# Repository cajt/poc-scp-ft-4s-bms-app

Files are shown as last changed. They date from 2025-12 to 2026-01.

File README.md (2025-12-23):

# poc-scp-ft-4s-bms-app
Proof of concept fault tolerant SCP with a BMS Application.

# Fault Tolerance Concept

Fail-safe in a 2-out-of-2 configuration. BMS is implemented in split parts. Both halves have to error 
free for the battery/BMS to operate nominally. 
If an error is detected the whole system stops and the electronics disconnects the battery cells from 
the rest of the system, protecting the cells from leaving their safe operating area in the presence 
of BMS error.

In the error-free operation simple cell safety limits are checked: Cell voltages, Current and Temperatures.

# Simplifications for the PoC

- Power supply: Non-redundant and externally supplied.
- Wake-up and power boot-strap: None, the system can't wake up without an external power source. 
- Only 4 cells. (But it should moderately obvious how to extend this by a few more cells. Conceptually this is also compatible with stacking the BMS for higher cells counts.)

# Motivation

Li based cells have some nasty failure-modes, and require some attention to avoid entering dangerous operating areas. This is a good application for fault-tolerance and fail-safe circuitry

# Disclaimer, Liabilities and Guarantees

No Guarantees. The risk is yours alone. If you don't understand this method, mitigation and risks involved you should really not touch this. 
Published in the hope that it might be inspiration or food for thought, not a ready to use module or product.

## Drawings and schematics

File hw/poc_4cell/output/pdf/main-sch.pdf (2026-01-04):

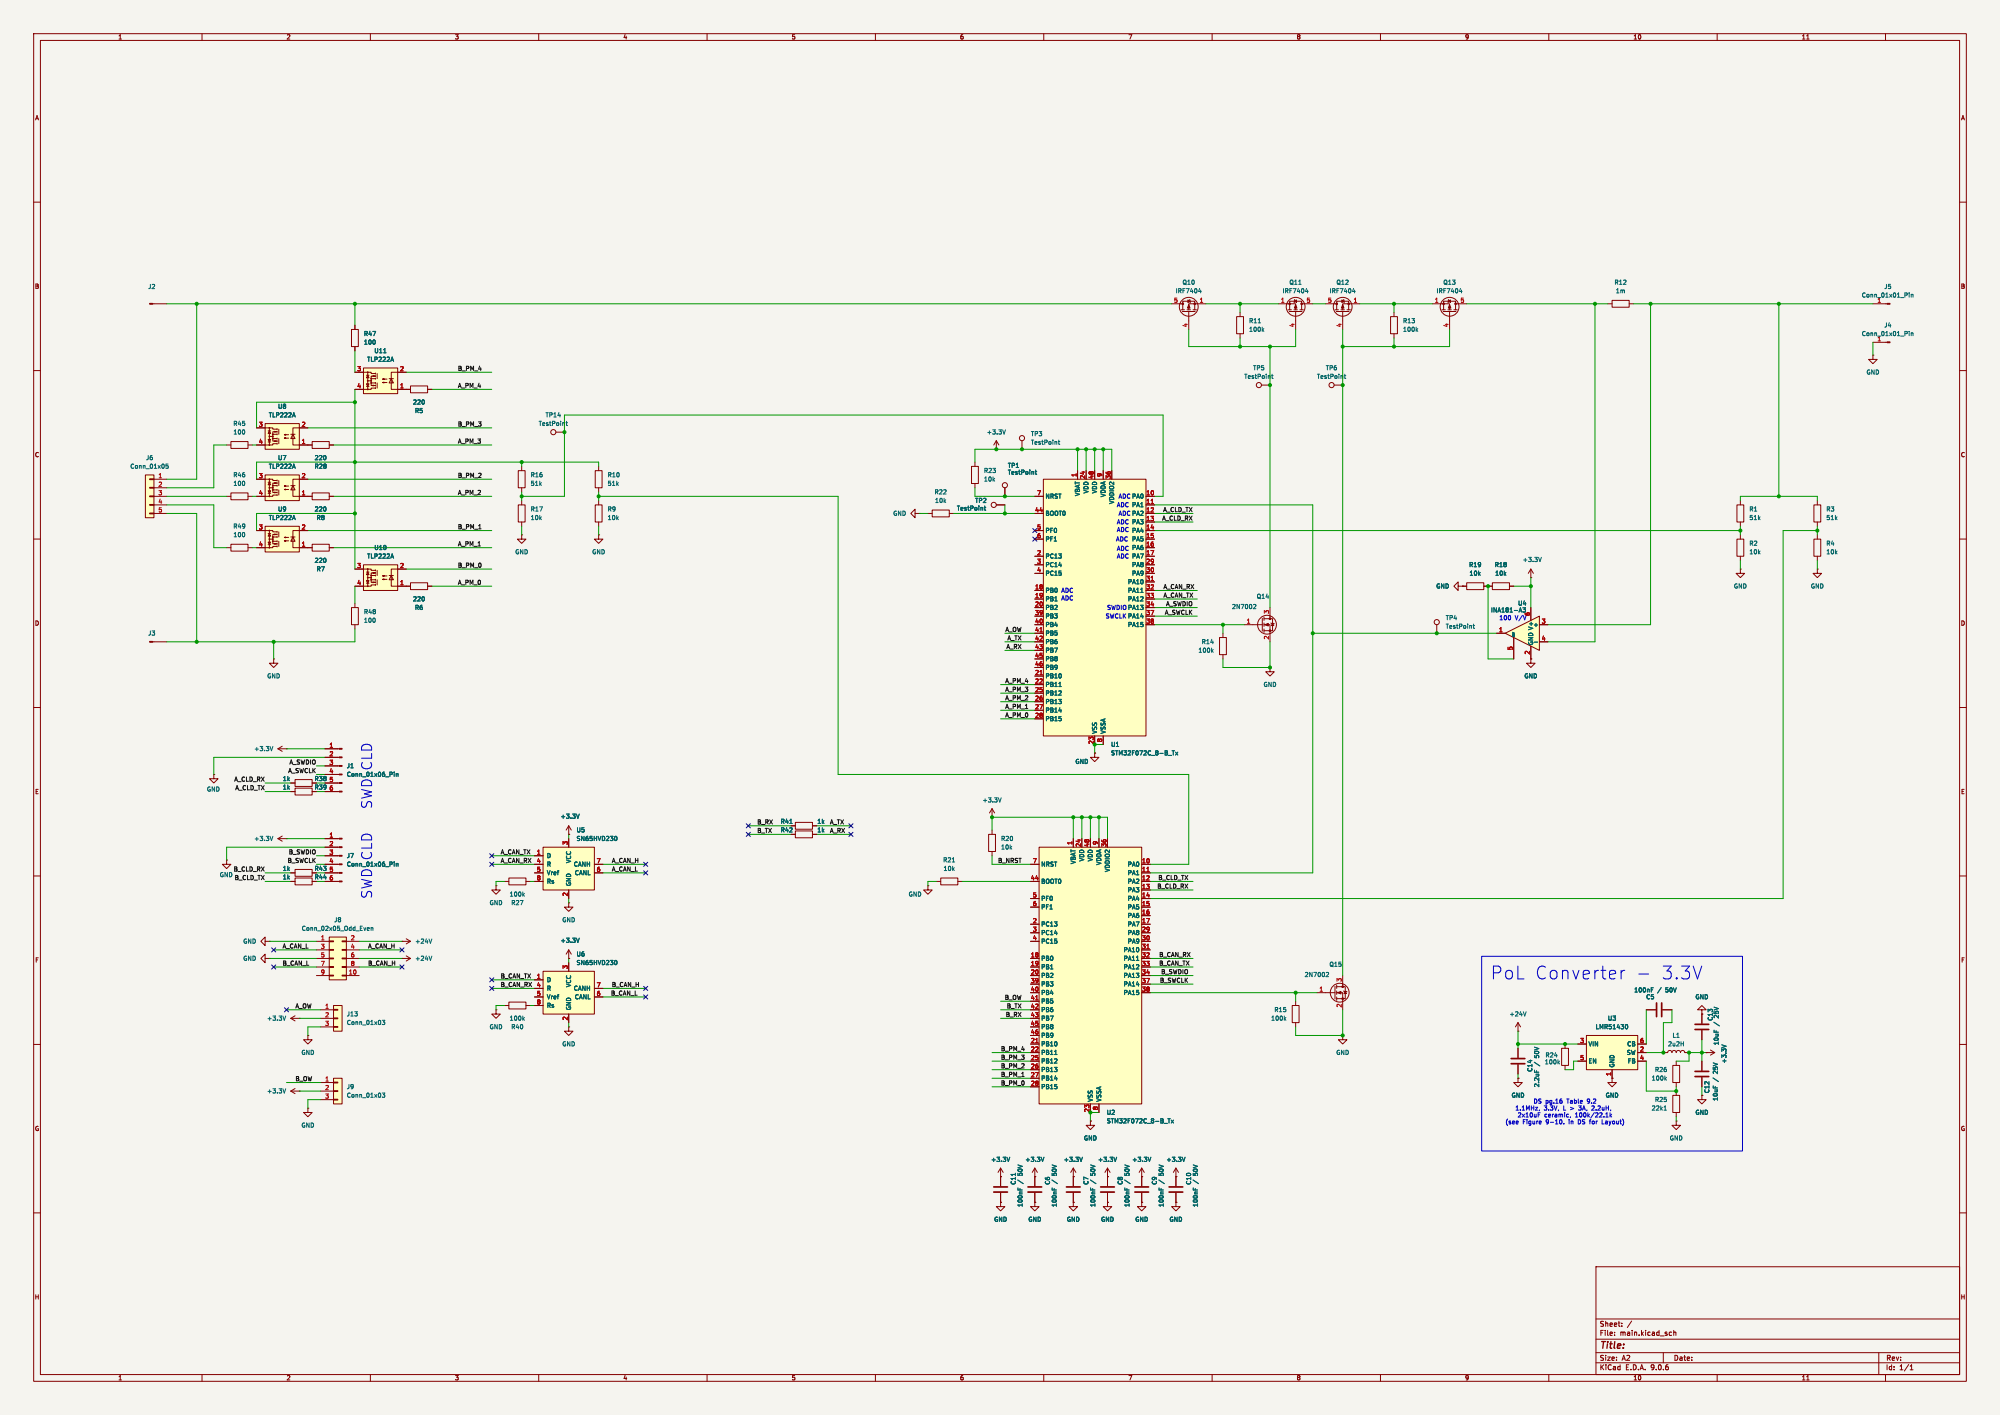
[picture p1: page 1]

1 VDD 24 VDD 48 VSS 23 VDDA

ADC CLD SWD CLD SWD

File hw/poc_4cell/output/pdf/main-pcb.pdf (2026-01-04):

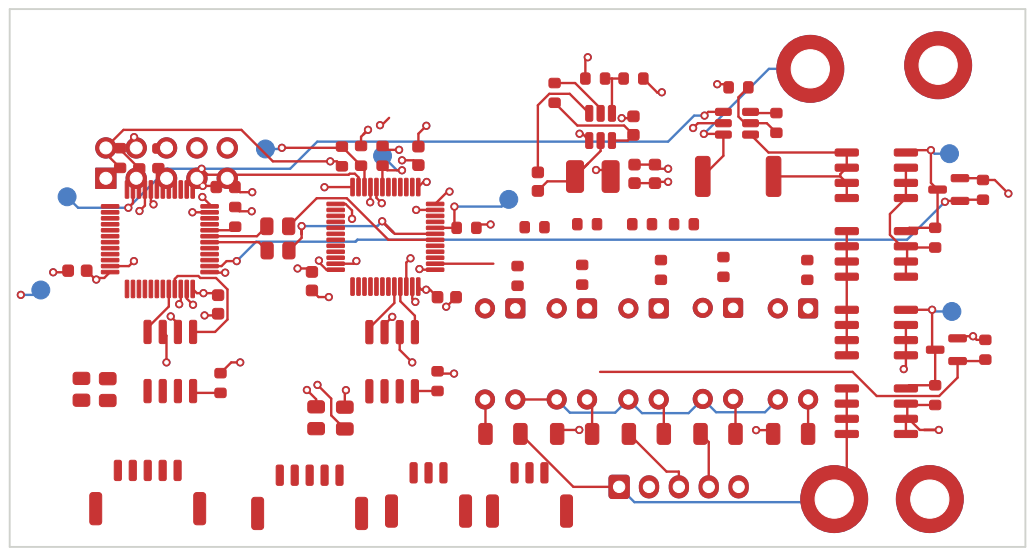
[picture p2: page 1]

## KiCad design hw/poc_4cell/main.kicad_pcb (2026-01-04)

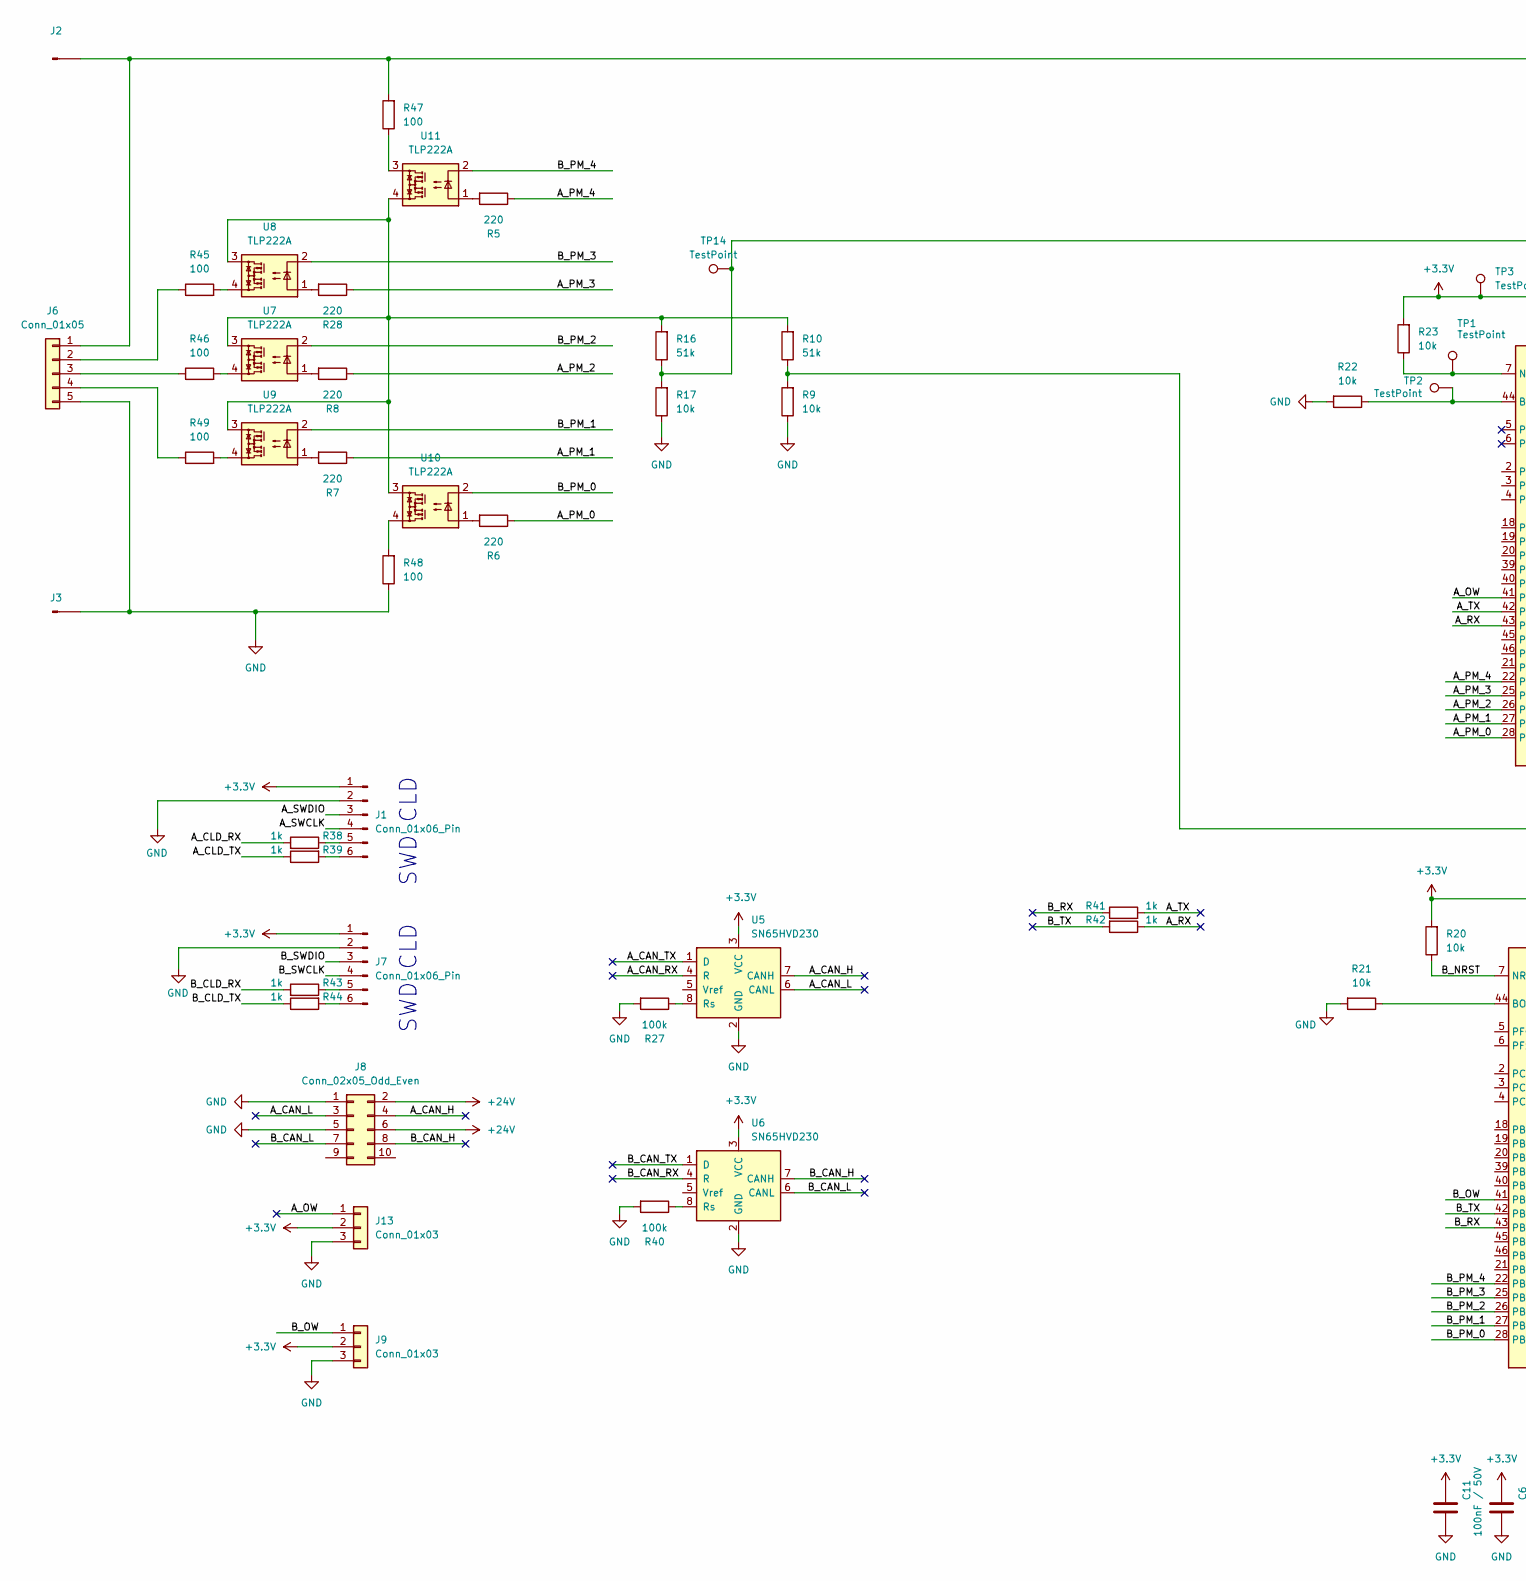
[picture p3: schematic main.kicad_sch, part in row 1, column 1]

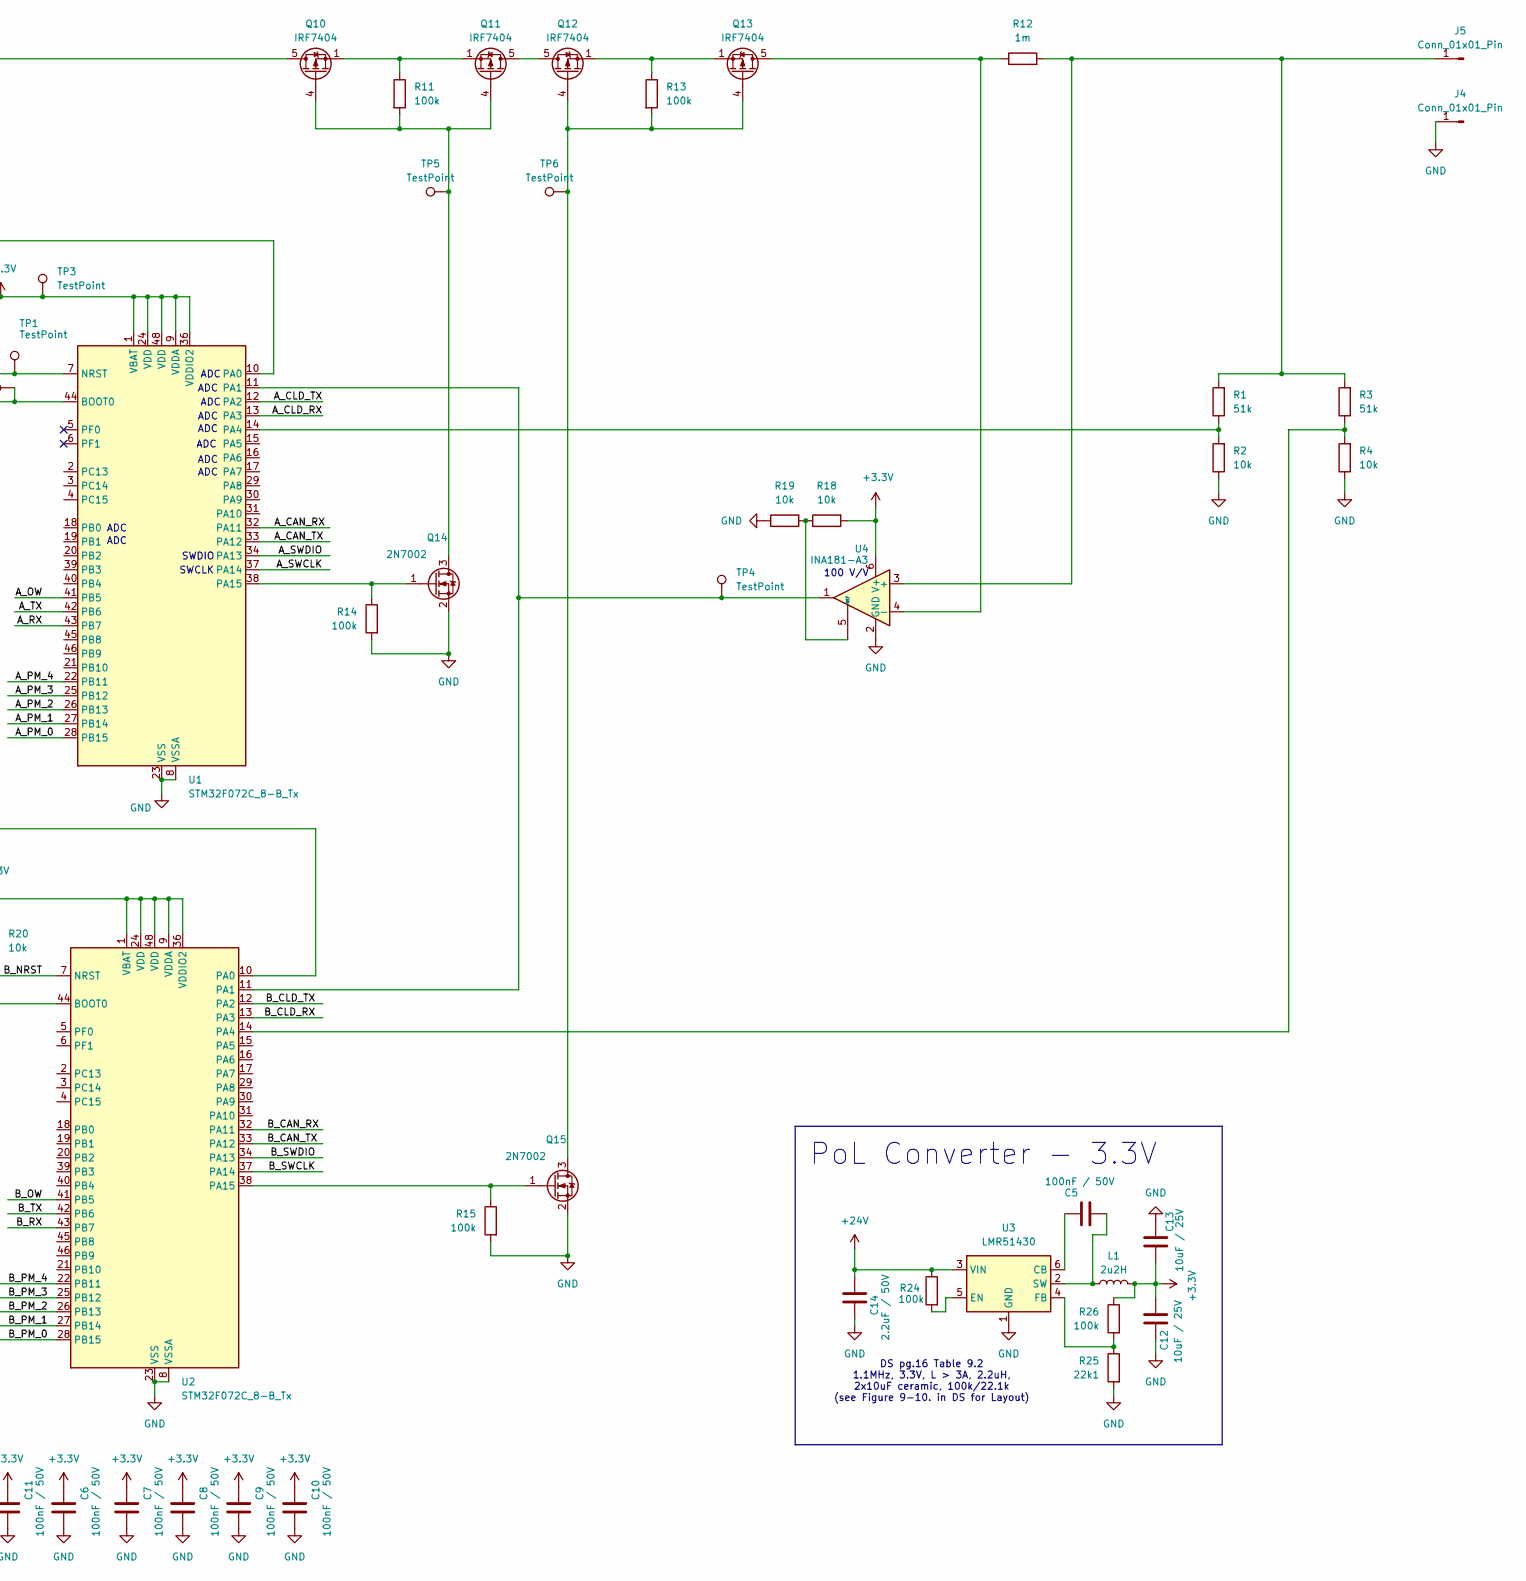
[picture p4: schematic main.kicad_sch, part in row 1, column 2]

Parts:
C5, C6, C7, C8, C9, C10, C11: 100nF / 50V; C_0603_1608Metric
C12, C13: 10uF / 25V; C_0603_1608Metric
C14: 2.2uF / 50V; C_0603_1608Metric
J1, J7: Conn_01x06_Pin; JST_GH_SM05B-GHS-TB_1x05-1MP_P1.25mm_Horizontal
J2, J3, J4, J5: Conn_01x01_Pin; MountingHole_3.2mm_M3_DIN965_Pad
J6: Conn_01x05; JST_XH_B5B-XH-AM_1x05_P2.50mm_Vertical
J8: Conn_02x05_Odd_Even; PinHeader_2x05_P2.54mm_Horizontal
J9, J13: Conn_01x03; JST_GH_SM03B-GHS-TB_1x03-1MP_P1.25mm_Horizontal
L1: 2u2H; L_1210_3225Metric_Pad1.42x2.65mm_HandSolder; mfg# DFE322520F-2R2M=P2
Q10, Q11, Q12, Q13: IRF7404; SOIC-8_3.9x4.9mm_P1.27mm
Q14, Q15: 2N7002; SOT-23
R1, R3, R10, R16: 51k; R_0603_1608Metric
R2, R4, R9, R17, R18, R19, R20, R21, R22, R23: 10k; R_0603_1608Metric
R5, R6, R7, R8, R28: 220; R_0603_1608Metric
R11, R13, R14, R15, R24, R26, R27, R40: 100k; R_0603_1608Metric
R12: 1m; R_2512_6332Metric
R25: 22k1; R_0603_1608Metric
R38, R39, R41, R42, R43, R44: 1k; R_0805_2012Metric
R45, R46, R47, R48, R49: 100; R_1206_3216Metric
TP1, TP2, TP3, TP4, TP5, TP6, TP14: TestPoint; TestPoint_Pad_D1.5mm
U1, U2: STM32F072C_8-B_Tx; LQFP-48_7x7mm_P0.5mm
U3: LMR51430; SOT-23-6
U4: INA181-A3; SOT-23-6
U5, U6: SN65HVD230; SOIC-8_3.9x4.9mm_P1.27mm
U7, U8, U9, U10, U11: TLP222A; DIP-4_W7.62mm

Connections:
+3.3V: C6.1, C7.1, C8.1, C9.1, C10.1, C11.1, C12.1, C13.1, J1.1, J7.1, J9.2, J13.2, L1.2, R18.2, R20.2, R23.2, R26.1, TP3.1, U1.1 (VBAT), U1.9 (VDDA), U1.24 (VDD), U1.36 (VDDIO2), U1.48 (VDD), U2.1 (VBAT), U2.9 (VDDA), U2.24 (VDD), U2.36 (VDDIO2), U2.48 (VDD), U4.6 (V+), U5.3 (VCC), U6.3 (VCC)
+24V: C14.1, J8.2, J8.6, R24.1, U3.3 (VIN)
/A_CAN_H: J8.4, U5.7 (CANH)
/A_CAN_L: J8.3, U5.6 (CANL)
/A_CAN_RX: U1.32 (PA11), U5.4 (R)
/A_CAN_TX: U1.33 (PA12), U5.1 (D)
/A_CLD_RX: R38.2, U1.13 (PA3)
/A_CLD_TX: R39.1, U1.12 (PA2)
/A_OW: J13.1, U1.41 (PB5)
/A_PM_0: R6.1, U1.28 (PB15)
/A_PM_1: R7.1, U1.27 (PB14)
/A_PM_2: R8.1, U1.26 (PB13)
/A_PM_3: R28.1, U1.25 (PB12)
/A_PM_4: R5.1, U1.22 (PB11)
/A_RX: R42.1, U1.43 (PB7)
/A_SWCLK: J1.4, U1.37 (PA14)
/A_SWDIO: J1.3, U1.34 (PA13)
/A_TX: R41.2, U1.42 (PB6)
/B_CAN_H: J8.8, U6.7 (CANH)
/B_CAN_L: J8.7, U6.6 (CANL)
/B_CAN_RX: U2.32 (PA11), U6.4 (R)
/B_CAN_TX: U2.33 (PA12), U6.1 (D)
/B_CLD_RX: R43.2, U2.13 (PA3)
/B_CLD_TX: R44.1, U2.12 (PA2)
/B_NRST: R20.1, U2.7 (NRST)
/B_OW: J9.1, U2.41 (PB5)
/B_PM_0: U2.28 (PB15), U10.2
/B_PM_1: U2.27 (PB14), U9.2
/B_PM_2: U2.26 (PB13), U7.2
/B_PM_3: U2.25 (PB12), U8.2
/B_PM_4: U2.22 (PB11), U11.2
/B_RX: R41.1, U2.43 (PB7)
/B_SWCLK: J7.4, U2.37 (PA14)
/B_SWDIO: J7.3, U2.34 (PA13)
/B_TX: R42.2, U2.42 (PB6)
GND: C6.2, C7.2, C8.2, C9.2, C10.2, C11.2, C12.2, C13.2, C14.2, J1.2, J3.1, J4.1, J6.5, J7.2, J8.1, J8.5, J9.3, J13.3, Q14.2 (S), Q15.2 (S), R2.1, R4.1, R9.1, R14.2, R15.2, R17.1, R19.1, R21.2, R22.2, R25.2, R27.2, R40.2, R48.1, U1.8 (VSSA), U1.23 (VSS), U1.35 (VSS), U1.47 (VSS), U2.8 (VSSA), U2.23 (VSS), U2.35 (VSS), U2.47 (VSS), U3.1 (GND), U4.2 (GND), U5.2 (GND), U6.2 (GND)
unnamed: J1.5, R38.1
unnamed: J1.6, R39.2
unnamed: J2.1, J6.1, Q10.5 (D), Q10.6 (D), Q10.7 (D), Q10.8 (D), R47.2
unnamed: J5.1, R1.2, R3.2, R12.2, U4.3 (+)
unnamed: J6.2, R45.1
unnamed: J6.3, R46.1
unnamed: J6.4, R49.1
unnamed: J7.5, R43.1
unnamed: J7.6, R44.2
unnamed: Q10.4 (G), Q11.4 (G), Q14.3 (D), R11.2, TP5.1
unnamed: Q10.1 (S), Q10.2 (S), Q10.3 (S), Q11.1 (S), Q11.2 (S), Q11.3 (S), R11.1
unnamed: Q11.5 (D), Q11.6 (D), Q11.7 (D), Q11.8 (D), Q12.5 (D), Q12.6 (D), Q12.7 (D), Q12.8 (D)
unnamed: Q12.4 (G), Q13.4 (G), Q15.3 (D), R13.2, TP6.1
unnamed: Q12.1 (S), Q12.2 (S), Q12.3 (S), Q13.1 (S), Q13.2 (S), Q13.3 (S), R13.1
unnamed: Q14.1 (G), R14.1, U1.38 (PA15)
unnamed: Q15.1 (G), R15.1, U2.38 (PA15)
unnamed: R5.2, U11.1
unnamed: R6.2, U10.1
unnamed: R7.2, U9.1
unnamed: R8.2, U7.1
unnamed: R10.2, R16.2, U7.3, U8.3, U9.3, U10.3, U11.4
unnamed: R28.2, U8.1
unnamed: R45.2, U8.4
unnamed: R46.2, U7.4
unnamed: R47.1, U11.3
unnamed: R48.2, U10.4
unnamed: R49.2, U9.4
unnamed: R22.1, TP2.1, U1.44 (BOOT0)
unnamed: R23.1, TP1.1, U1.7 (NRST)
unnamed: R16.1, R17.2, TP14.1, U1.10 (PA0)
unnamed: TP4.1, U1.11 (PA1), U2.11 (PA1), U4.1
unnamed: R1.1, R2.2, U1.14 (PA4)
unnamed: R21.1, U2.44 (BOOT0)
unnamed: R9.2, R10.1, U2.10 (PA0)
unnamed: R3.1, R4.2, U2.14 (PA4)
unnamed: C5.1, U3.6 (CB)
unnamed: R24.2, U3.5 (EN)
unnamed: R25.1, R26.2, U3.4 (FB)
unnamed: C5.2, L1.1, U3.2 (SW)
unnamed: Q13.5 (D), Q13.6 (D), Q13.7 (D), Q13.8 (D), R12.1, U4.4 (-)
unnamed: R18.1, R19.2, U4.5 (REF)
unnamed: R27.1, U5.8 (Rs)
unnamed: R40.1, U6.8 (Rs)

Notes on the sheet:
SWCLK
ADC
CLD
SWD
DS pg.16 Table 9.2 1.1MHz, 3.3V, L > 3A, 2.2uH, 2x10uF ceramic, 100k/22.1k (see Figure 9-10. in DS for Layout)
PoL Converter - 3.3V
100 V/V
SWDIO

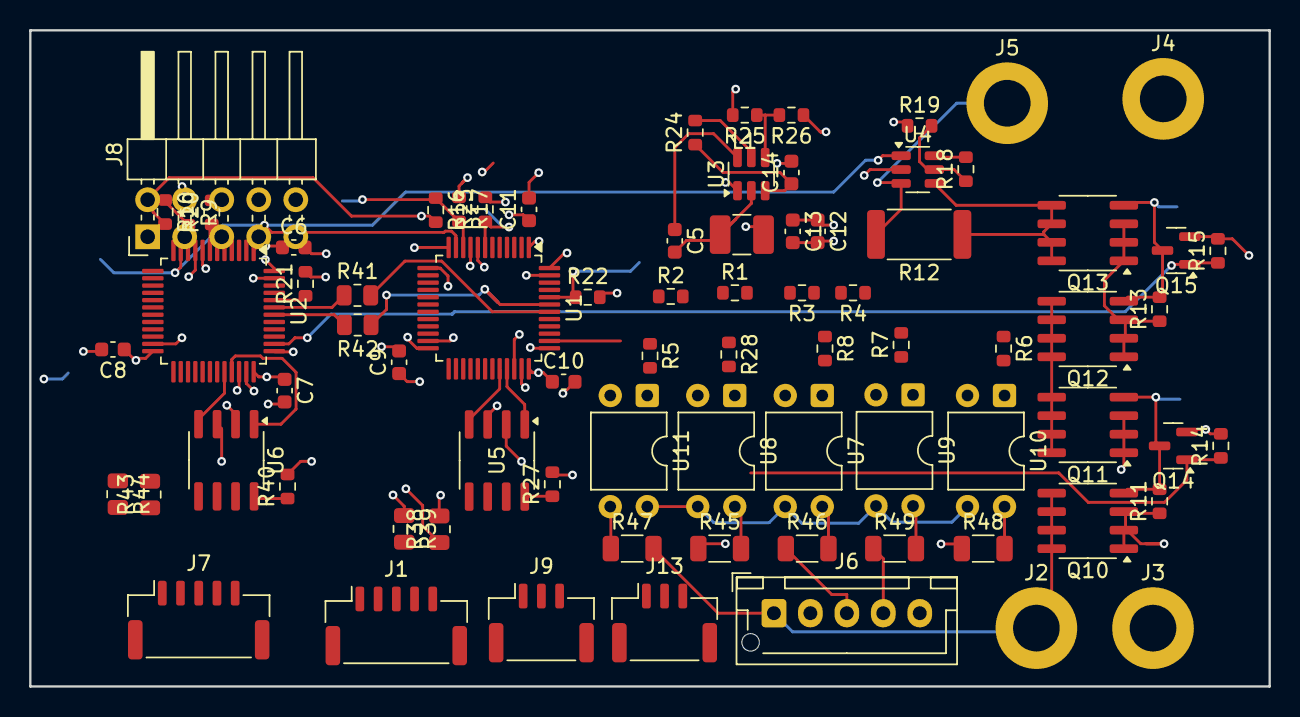
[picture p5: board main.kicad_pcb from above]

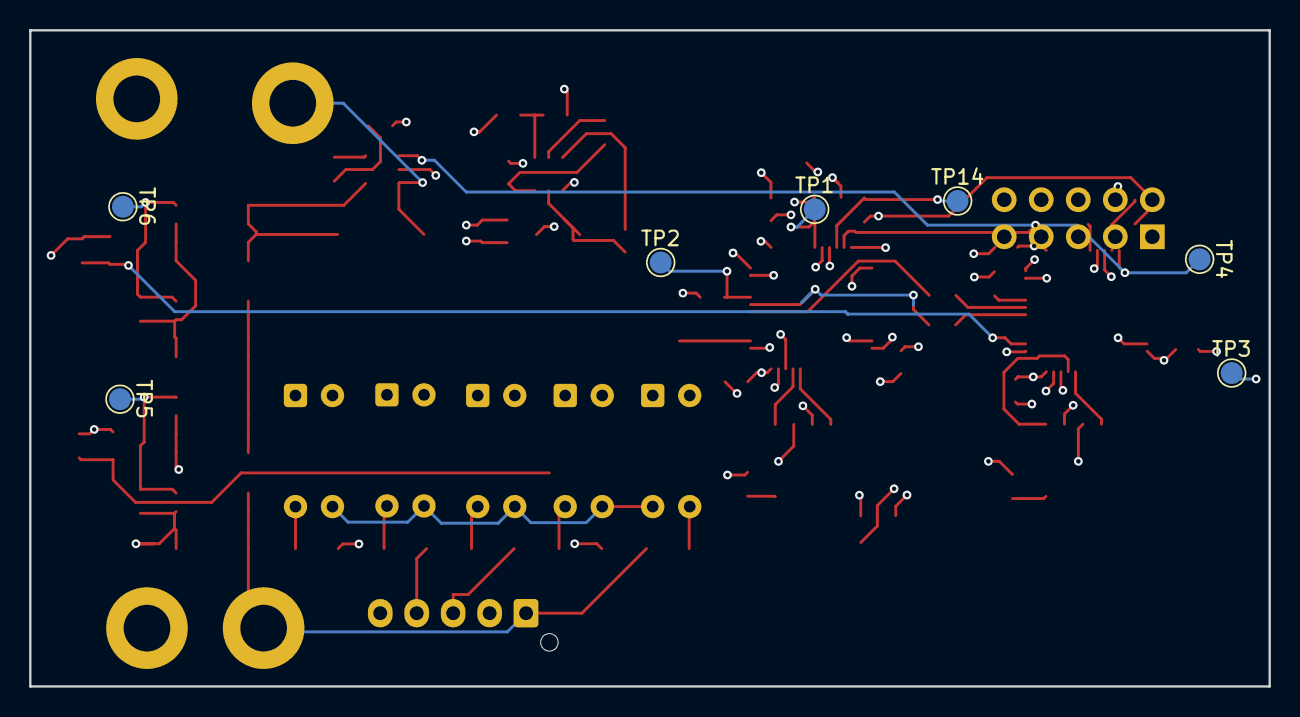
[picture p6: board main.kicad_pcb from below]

Board: 4 copper layers, 85.0 x 45.0 mm, 85 parts (7 on the bottom side), 77 nets.
